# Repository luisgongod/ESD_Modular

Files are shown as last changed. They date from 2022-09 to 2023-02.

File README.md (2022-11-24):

# E.S.D.
<!-- 
 _____ _____ ____  
|   __|   __|    \ 
|   __|__   |  |  |
|_____|_____|____/ 
 -->

Main repo for *ESD* Eurorack modules. 

## !!! Attention: Both Models are under Beta, bugs and fixes are in process !!!

- [*Model 14*](https://github.com/luisgongod/ESD_Modular/tree/main/model_14): an inspired _EuroPi_ module with 4 extra CVs, 4 Pots, 1 Digital Inpu, Bigger screen and I/O headers
- [*Model 15*](https://github.com/luisgongod/ESD_Modular/tree/main/model_15): Remix of the OG _EuroPi_ adding CV to the existing Pots and I/O headers for external modules

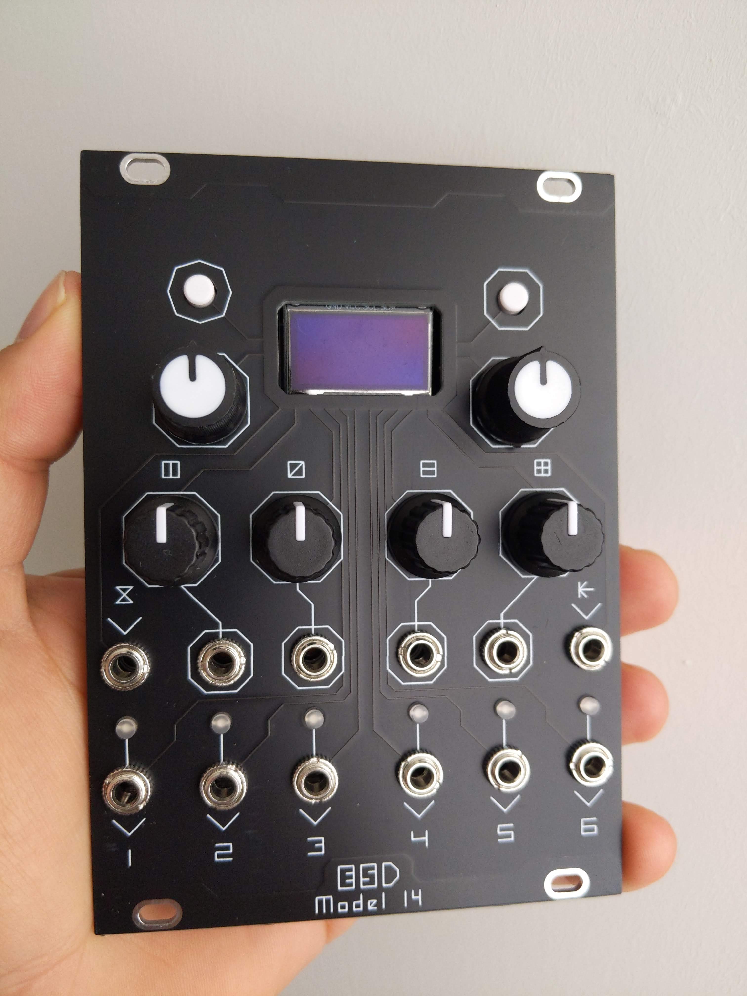
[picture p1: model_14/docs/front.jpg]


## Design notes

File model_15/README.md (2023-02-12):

# Model 15

Programable Eurorack module Remix of by Allen-Synthesis' [EuroPi](https://github.com/Allen-Synthesis/EuroPi).

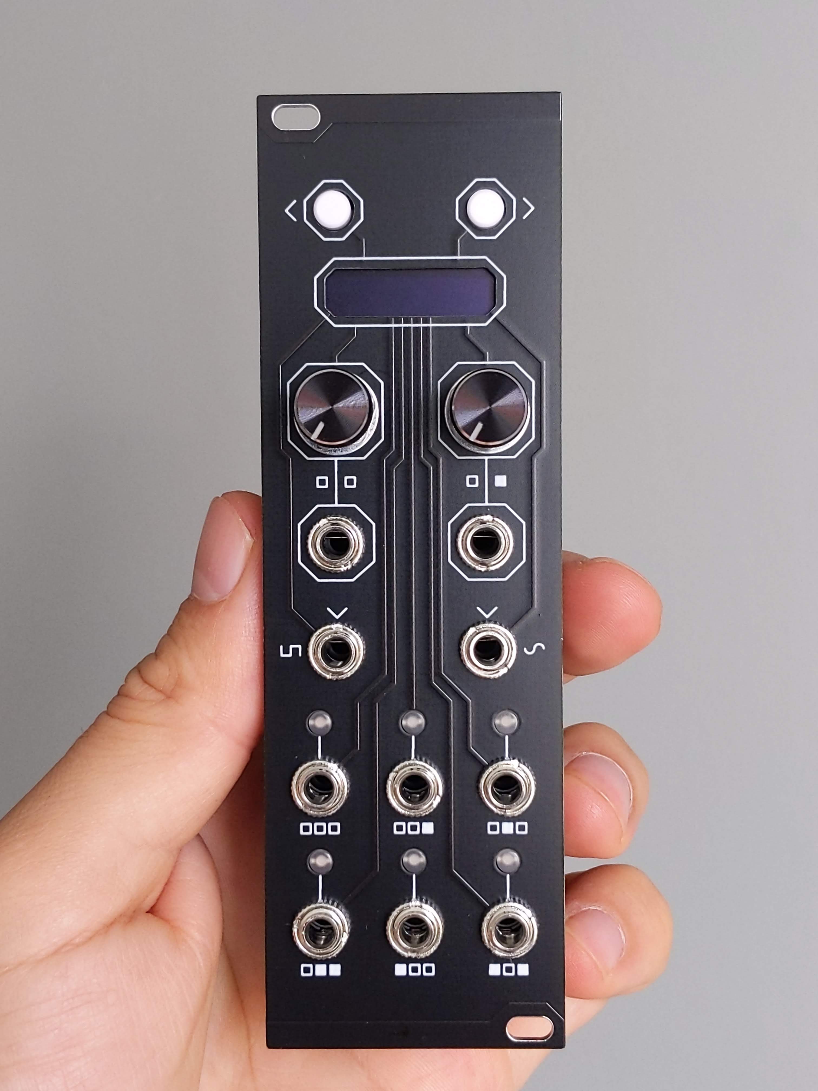
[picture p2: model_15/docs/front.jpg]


## Description

This module is based on the schematics of the EuroPi, the slight differences:

- Added CV to the Knobs (analogue input)
- Access to un-used pins thru a header (for expansions)
- Jumper to change analog input from bipolar-unipolar* (Experimental! see TODOS)

This module is fully compatible with all Europi [scripts](https://github.com/Allen-Synthesis/EuroPi/tree/main/software/contrib) as long as the modified firmware is used `europi_m15.py`.

## TODOs:

- Better Diagnosis Script
- Change Calibration to acommodate bipolar and inverted Analog signal
- Add Bipolar support (change fw)

## Get your own

Under `hardwared` you can find the gerbers and BOM files. This gerber was done to be printed in one go, a v-cut is used to separate both pcnbs. Be careful about it when ordering. Exported files to `altium` are also included but _atention_ these were not verified (i dont have altium)

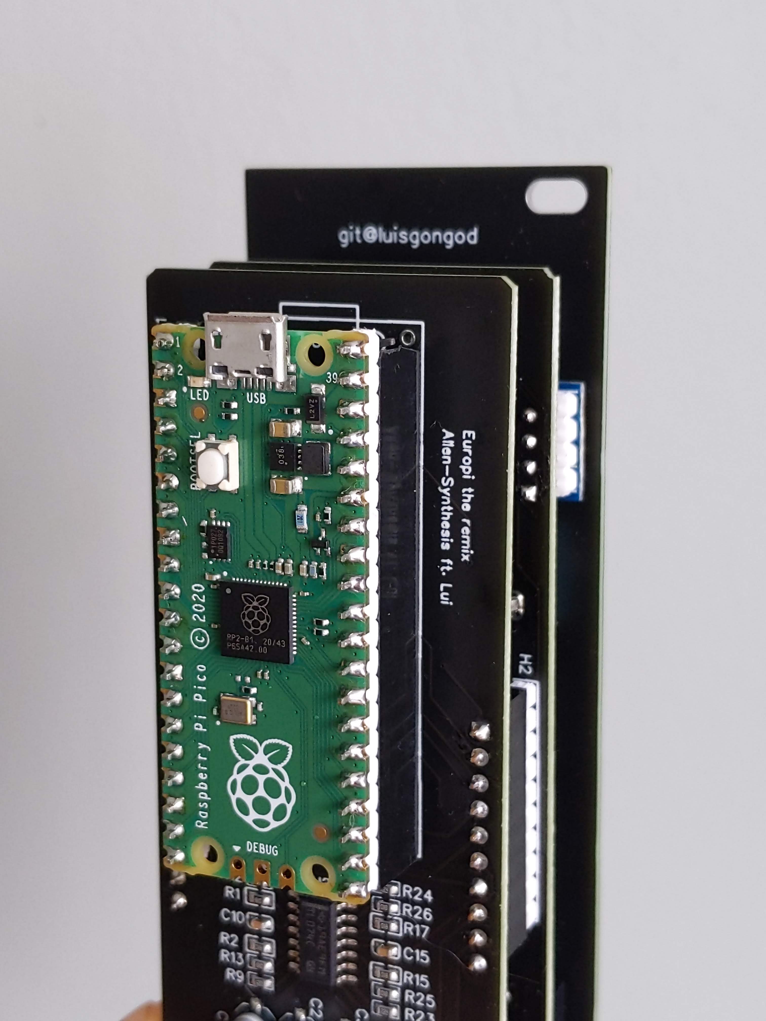
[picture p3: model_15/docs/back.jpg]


## Get Started

You can use the same setup as decribed in EuroPi's page ([here](https://github.com/Allen-Synthesis/EuroPi/blob/main/software/programming_instructions.md)). 

If you want to use `menu.py` script as `main.py`. Use `ampy` pip package to move files to the `contrib` folder

```
 C:\EuroPi-main\software> ampy  --port COM21 put contrib /lib/contrib
```
 
Other useful `ampy` commands can be found [here](https://learn.adafruit.com/micropython-basics-load-files-and-run-code/file-operations)

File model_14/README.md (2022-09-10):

# Model 14

Programable Eurorack module inspired by Allen-Synthesis' [EuroPi](https://github.com/Allen-Synthesis/EuroPi).



## Description

This module is based on the schematics of the EuroPi, the main differences are:

- 7 extra Analogue inputs thanks to a multiplexer
- Larger 128x64 Oled display
- Extra digital input
- Access to un-used pins thru a header (for expansions)
- Jumper to change analog input from bipolar-unipolar or range (10Vpp or 5Vpp)

This module is fully compatible with all Europi [scripts](https://github.com/Allen-Synthesis/EuroPi/tree/main/software/contrib) using the midified firmware `europi_m14.py` (more details below).

## Get your own

Under `hardwared` you can find the gerbers and BOM files. _Caution_,  this last version of the hardware files was not produced, there was a small bug: the LEDs where not connected, you can see maybe that the ground needed to be wire in:

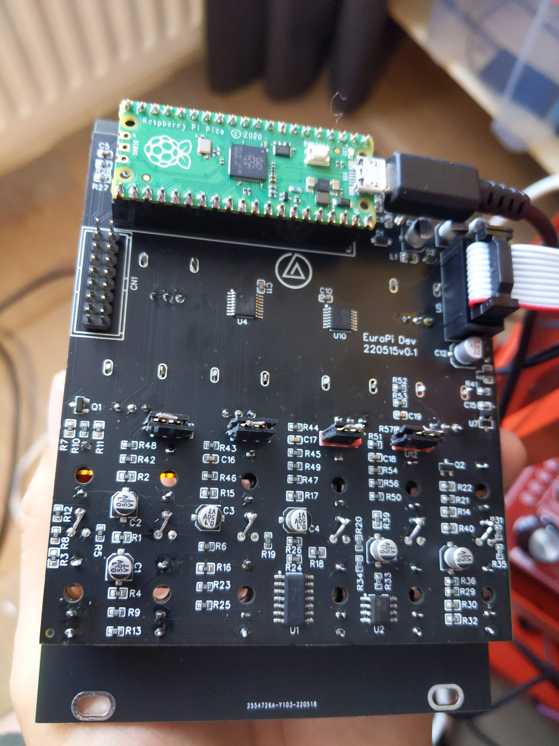
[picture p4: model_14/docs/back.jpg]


However I am confident that the module will work if manufactured as it is. Some assistant to debugging could be provided. Components are relatively easty to source and because of the nature of the I/O there is no need for high accuracy resistors (1% is ok). Calibrating the module is a most.

## Get Started

You can use the same setup as decribed in EuroPi's page ([here](https://github.com/Allen-Synthesis/EuroPi/blob/main/software/programming_instructions.md)). Once everything is installed, you can save the `europi_m14.py` file in the `libs` folder. You can also change the name and overwrite the `europi.py`, this will make all original scripts work right away. 
I have modified some of the scripts from the compilation to work with _model 14_. In this scripts I use the suffix `m14` to differenciate from originals. All credits to original authors should be in the code itself.

## To continue

This was an experiment to make my own definition/expanse of the Europi. I faced a few challenges but learn a lot. I want to focus on a different version. Perhaps if more people gets involved in increassing the scripts.

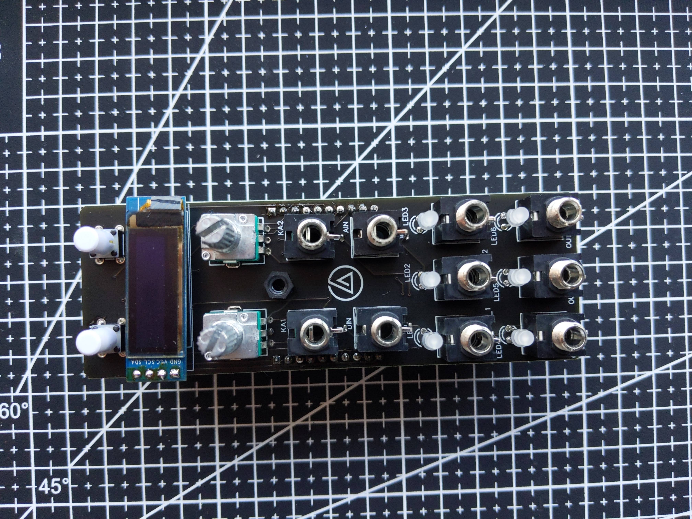
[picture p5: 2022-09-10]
model_15/docs/front_io.jpg

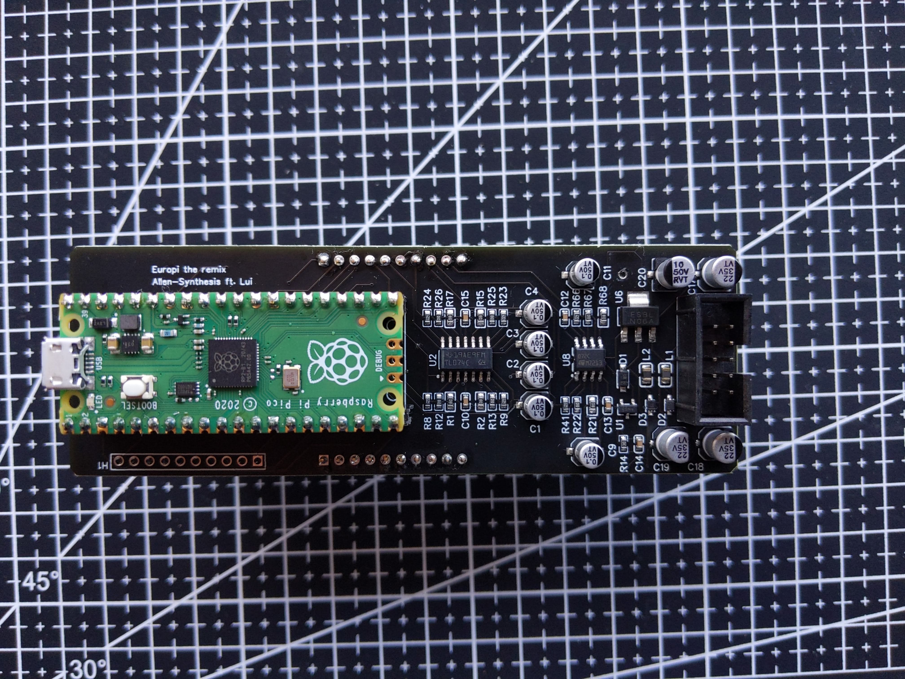
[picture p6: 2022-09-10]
model_15/docs/back_io.jpg

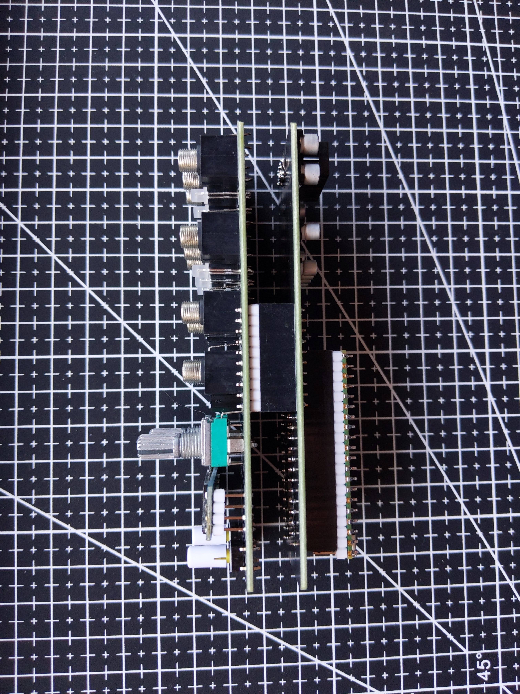
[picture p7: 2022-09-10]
model_15/docs/side.jpg

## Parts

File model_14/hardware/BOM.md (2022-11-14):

# BOM Model 14
| ID | Name | Designator | Footprint | Quantity |
|----|---|---|---|---|
| 1  | 0.1uF | C1,C2,C3,C4,C6,C7 | CAP-SMD_BD4.0-L4.3-W4.3-FD | 6 |
| 2  | 100nF | C5,C8,C10,C11,C15 | C0603 | 5 |
| 3  | 22uF | C9,C12,C14 | CAP-SMD_BD5.0-L5.3-W5.3-FD | 3 |
| 4  | 10uF | C13 | CAP-SMD_BD5.0-L5.3-W5.3-FD | 1 |
| 5  | 10nF | C16,C17,C18,C19 | C0603 | 4 |
| 6  | THONKICONN JACK | CV1,CV2,IN1,IN2,IN3,IN4,OUT_1,OUT_2,OUT_3,OUT_4,OUT_5,OUT_6 | THONKICONN_JACK | 12 |
| 7  | 1N4148W_C81598 | D1 | SOD-123F_L2.7-W1.6-LS3.8-RD | 1 |
| 8  | 1N5819WS | D2,D3 | SOD-323_L1.8-W1.3-LS2.5-RD | 2 |
| 9  | KH-A2541WV-8P | H1 | HDR-TH_8P-P2.54-V-M | 1 |
| 10 | 600Ω | L1,L2 | L0805 | 2 |
| 11 | 204-10SURD/S530-A3-L | LED1,LED2,LED3,LED4,LED5,LED6 | LED-TH_BD3.0-P2.54-FD | 6 |
| 12 | B100K | PT-CV1,PT-CV2,PT-PAR1,PT-PAR2,PT-PAR3,PT-PAR4 | ALPHA9MM_TRIM | 6 |
| 13 | MMBT3904-C20526 | Q1,Q2 | SOT-23-3_L2.9-W1.3-P1.90-LS2.4-BR | 2 |
| 14 | 1K | R1,R2,R3,R4,R15,R16,R17,R18,R28,R30,R32,R38,R39,R40 | R0603 | 14 |
| 15 | 4.7kΩ | R5,R6,R19,R20,R29,R31 | R0603 | 6 |
| 16 | 300kΩ | R7,R14,R50,R52,R60,R61,R62,R63 | R0603 | 8 |
| 17 | 220kΩ | R8,R9,R23,R24,R34,R35 | R0603 | 6 |
| 18 | 100kΩ | R10,R12,R13,R21,R25,R26,R33,R36,R51,R53,R64,R65 | R0603 | 12 |
| 19 | 10kΩ | R27,R37,R58,R59 | R0603 | 4 |
| 20 | 2.2kΩ | R41 | R0603 | 1 |
| 21 | 1MΩ | R42,R43 | R0603 | 2 |
| 22 | 150kΩ | R54,R55,R56,R57 | R0603 | 4 |
| 23 | TL1105SPF250Q | SW1,SW2 | KEY-TH_4P-L6.0-W6.0-P4.50-LS7.5 | 2 |
| 24 | TL072CDT | U2 | SOIC-8_L5.0-W4.0-P1.27-LS6.0-BL | 1 |
| 25 | DISPLAY-OLED-128X64  | U3 |DISPLAY-OLED-128X64 | 1 |
| 26 | 74HC4051PW,118 | U4 | TSSOP-16_L5.0-W4.4-P0.65-LS6.4-BL  | 1 |
| 27 | 1761608-3 | U5 | IDC-TH_10P-P2.54-S2.54_L9.2-W20.3  | 1 |
| 28 | LM1117MP-5.0/TR | U6 | SOT-223-3_L6.5-W3.4-P2.30-LS7.0-BR | 1 |
| 29 | LM4040C10IDBZR | U7 | SOT-23-3_L3.0-W1.7-P0.95-LS2.9-BR  | 1 |
| 30 | JUMPER3 | U8,U9,U11,U12 | HDR-TH_3P-P2.54-V-M-A | 4 |
| 31 | RASPBERRY-PI-PICO | U13 | RASPBERRY-PI-PICO | 1 |
| 32 | TL074CDR | U1 | SOIC-14_L8.7-W3.9-P1.27-LS6.0-BL | 1 |
| 33 | MCP6004T-I/ST | U10 | TSSOP-14_L5.0-W4.4-P0.65-LS6.4-BL  | 1 |
| 34 | 1RWHT | B1,B2 | ButtonSwitch Caps  | 2 |

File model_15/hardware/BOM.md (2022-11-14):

# BOM Model 15

| ID | Name | Designator | Footprint | Quantity  |
|----|---|---|---|---|
| 1  | DISPLAY-OLED-128X32 | 1 | DISPLAY-OLED-128X32 | 1 |
| 2  | THONKICONN JACK | AIN,DIN,KA1,KA2,OUT_1,OUT_2,OUT_3,OUT_4,OUT_5,OUT_6 | THONKICONN_JACK | 10 |
| 3  | 0.1uF | C1,C2,C3,C4,C9,C11 | CAP-SMD_BD4.0-L4.3-W4.3-FD | 6 |
| 4  | 100nF | C5,C8,C10,C12,C13,C14,C15,C16 | C0603 | 8 |
| 5  | 10nF | C6,C7,C21 | C0603 | 3 |
| 6  | 22uF | C17,C18,C19 | CAP-SMD_BD5.0-L5.3-W5.3-FD | 3 |
| 7  | 10uF | C20 | CAP-SMD_BD5.0-L5.3-W5.3-FD | 1 |
| 8  | 1N4148W_C81598 | D1 | SOD-123F_L2.7-W1.6-LS3.8-RD | 1 |
| 9  | 1N5819WS | D2,D3 | SOD-323_L1.8-W1.3-LS2.5-RD | 2 |
| 10 | Header-Male-2.54_1x10 | H1,H2,H4,H5,H6 | HDR-TH_10P-P2.54-V-M-1 | 5 |
| 11 | B100K | K1,K2 | ALPHA9MM_TRIM | 2 |
| 12 | 600Ω | L1,L2 | L0805 | 2 |
| 13 | 204-10SURD/S530-A3-L  | LED1,LED2,LED3,LED4,LED5,LED6 | LED-TH_BD3.0-P2.54-FD | 6 |
| 14 | PAD | PIN1 | PADPAD | 1 |
| 15 | MMBT3904-C20526 | Q1 | SOT-23-3_L2.9-W1.3-P1.90-LS2.4-BR | 1 |
| 16 | 1K | R1,R2,R3,R4,R15,R16,R17,R18,R21,R28,R38,R55,R64,R68 | R0603 | 14 |
| 17 | 4.7kΩ | R5,R6,R19,R20,R54,R65 | R0603 | 6 |
| 18 | 100kΩ | R7,R10,R12,R13,R22,R25,R26,R31,R39,R67 | R0603 | 10 |
| 19 | 220kΩ | R8,R9,R23,R24,R41,R66 | R0603 | 6 |
| 20 | 1MΩ | R11 | R0603 | 1  |
| 21 | 10kΩ | R14,R27,R37,R58 | R0603 | 4  |
| 22 | 150kΩ | R29,R30,R33,R34 | R0603 | 4  |
| 23 | 300kΩ | R32,R35,R36,R42,R43 | R0603 | 5  |
| 24 | TL1105SPF250Q | SW1,SW2 | KEY-TH_4P-L6.0-W6.0-P4.50-LS7.5 | 2  |
| 25 | LM4040C10IDBZR | U1 | SOT-23-3_L3.0-W1.7-P0.95-LS2.9-BR  | 1  |
| 26 | 1761608-3 | U5 | IDC-TH_10P-P2.54-S2.54_L9.2-W20.3  | 1  |
| 27 | LM1117MP-5.0/TR | U6 | SOT-223-3_L6.5-W3.4-P2.30-LS7.0-BR | 1  |
| 28 | TL072CDT | U8 | SOIC-8_L5.0-W4.0-P1.27-LS6.0-BL | 1  |
| 29 | RASPBERRY-PI-PICO | U13 | RASPBERRY-PI-PICO | 1  |
| 30 | TL074CDR | U2 | SOIC-14_L8.7-W3.9-P1.27-LS6.0-BL | 1  |
| 31 | MCP6004T-I/ST | U7 | TSSOP-14_L5.0-W4.4-P0.65-LS6.4-BL  | 1  |
| 32 | 1RWHT | B1,B2 | ButtonSwitch Caps  | 2 |

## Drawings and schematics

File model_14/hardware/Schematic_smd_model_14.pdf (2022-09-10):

# OUTPUTS

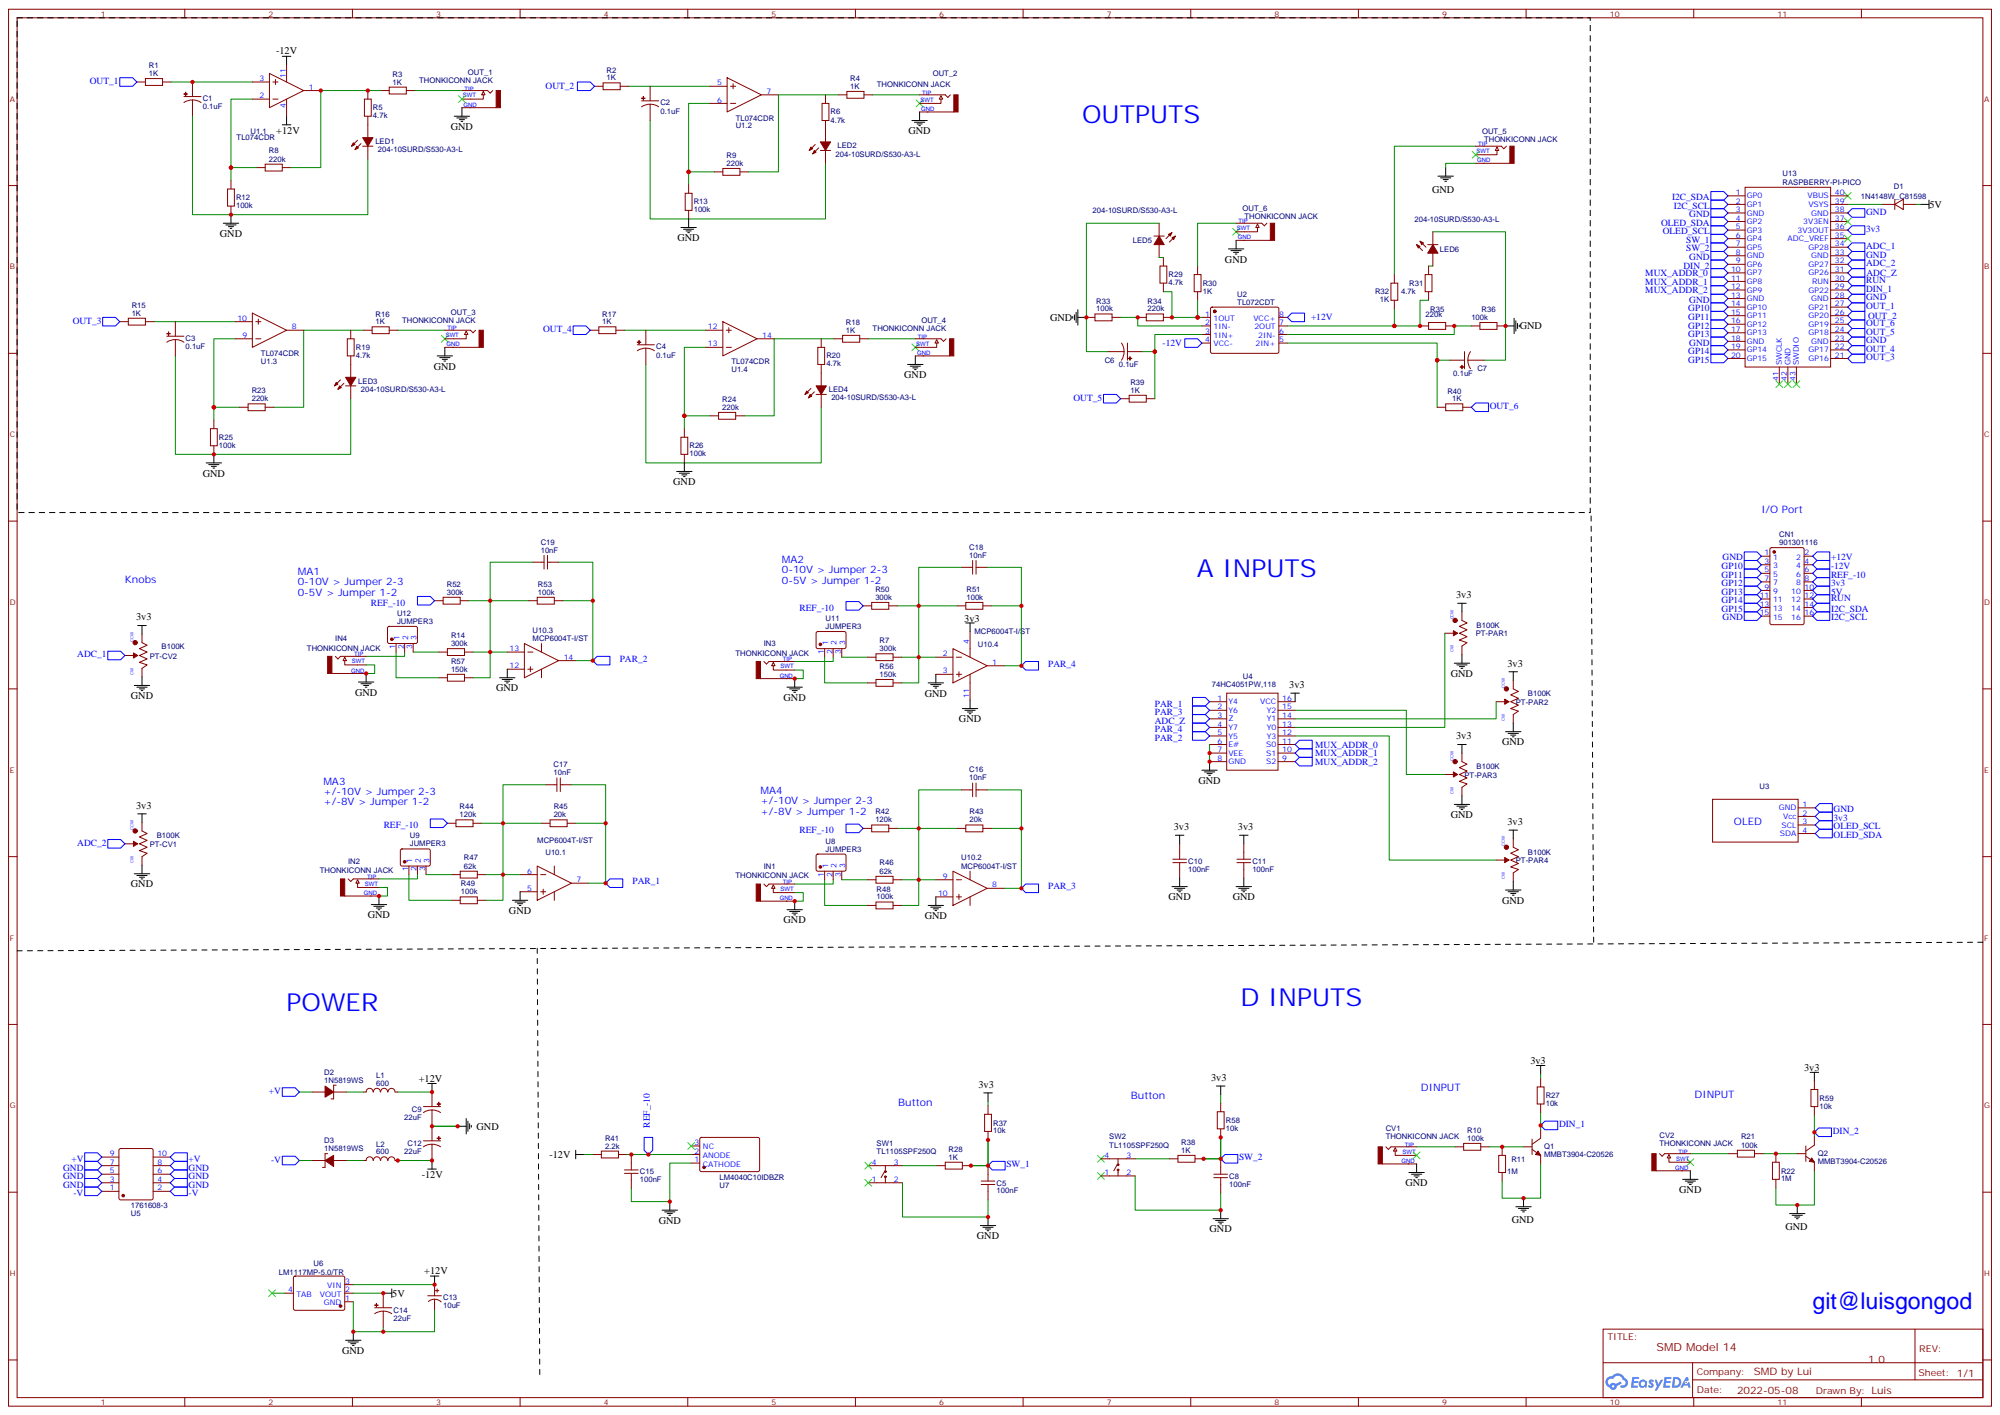
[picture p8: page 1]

Company: SMD by Lui

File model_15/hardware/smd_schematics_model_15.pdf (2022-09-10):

# OUT

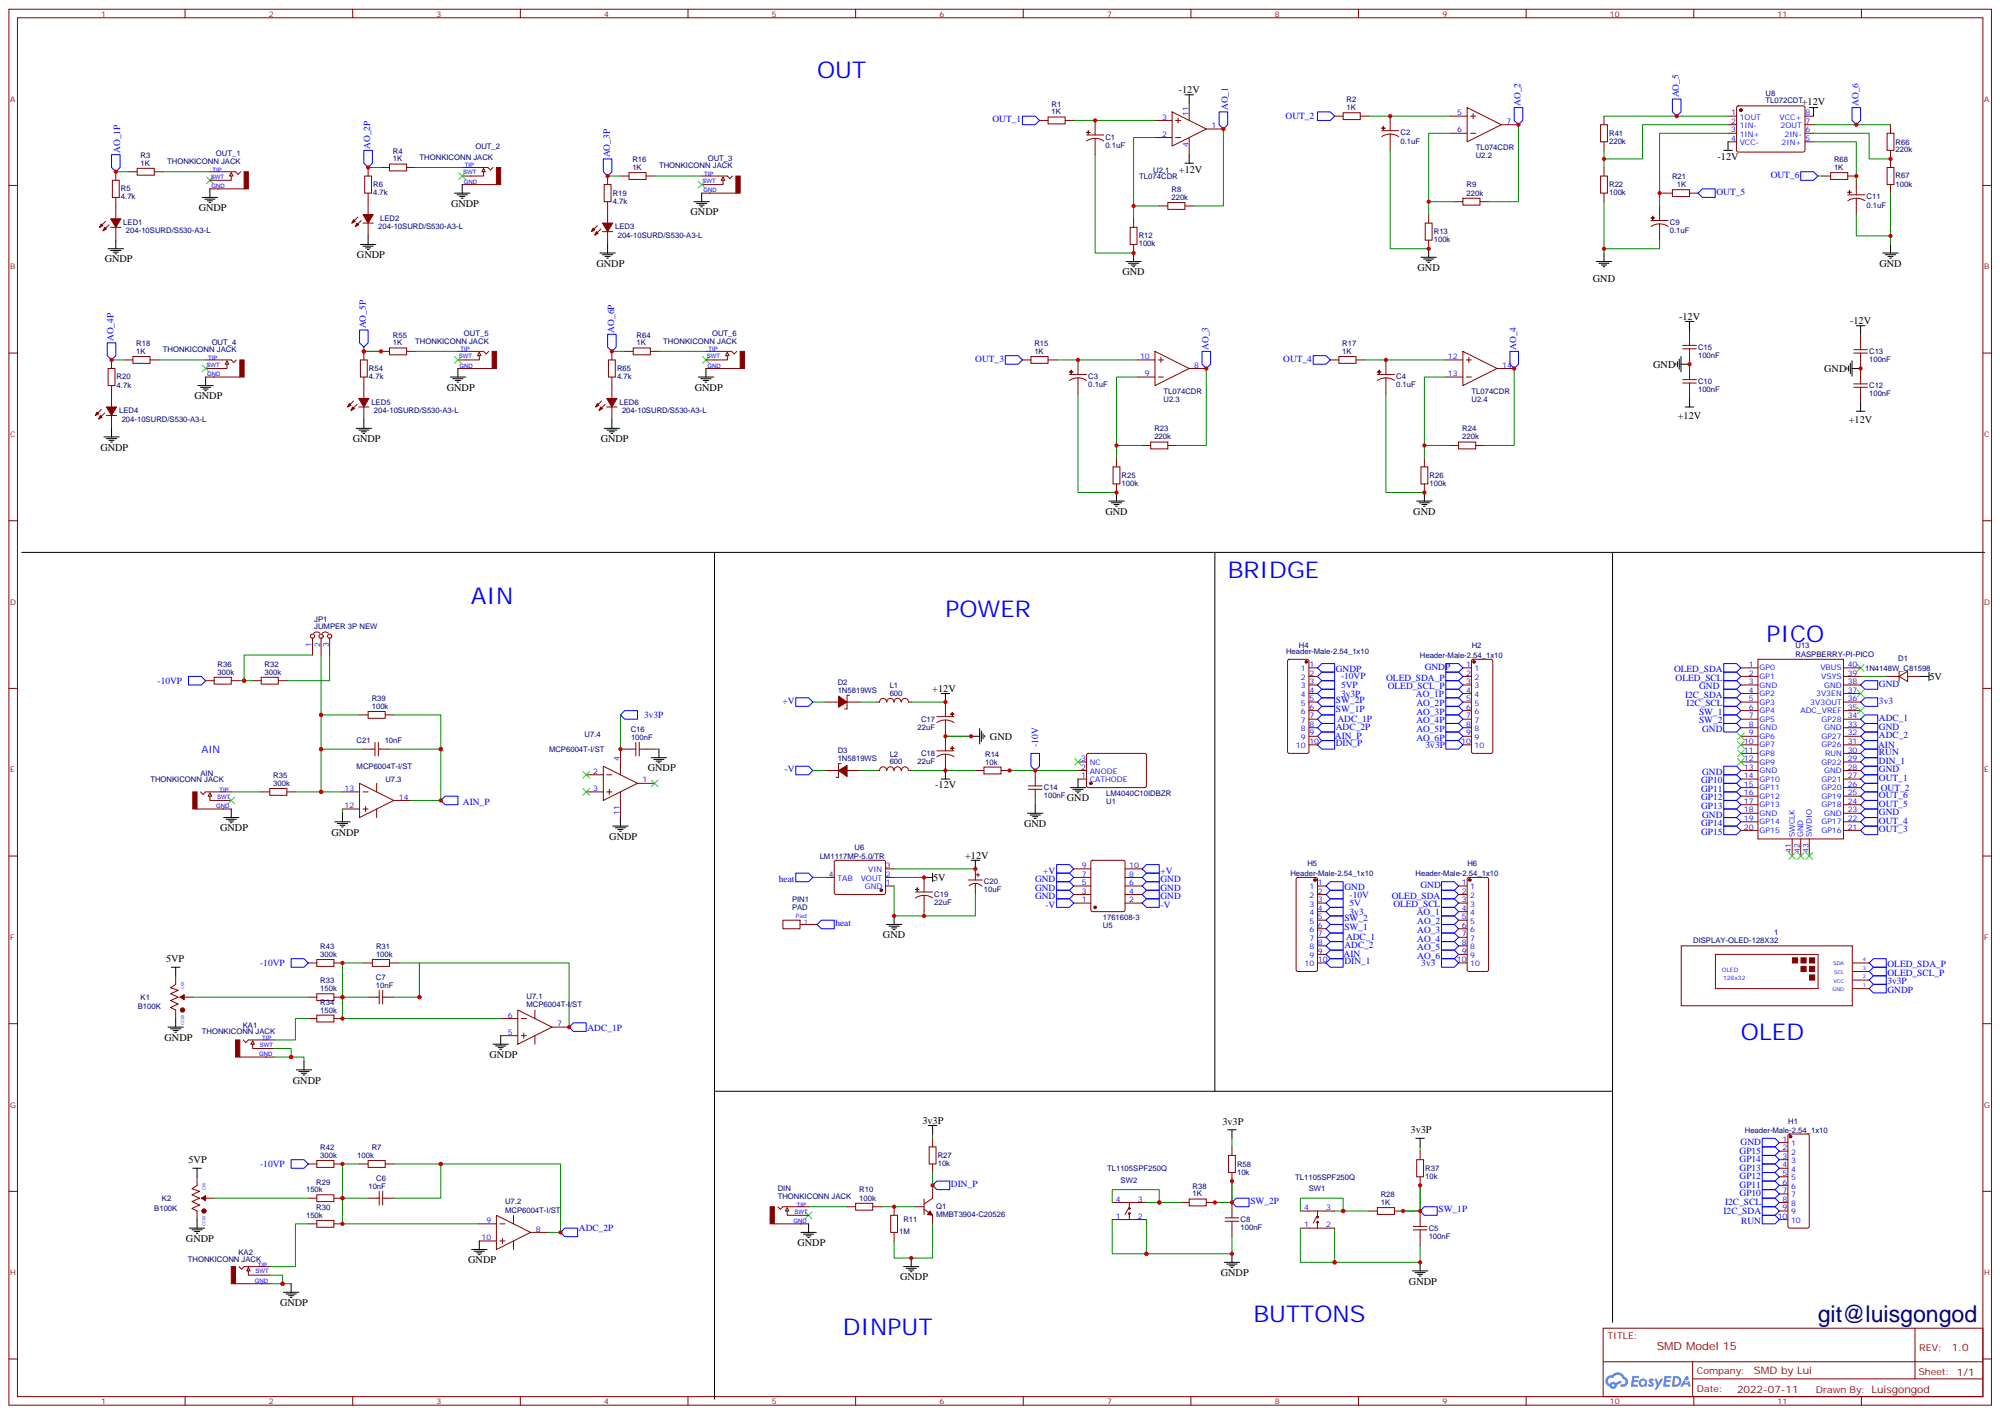
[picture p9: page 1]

Company: SMD by Lui

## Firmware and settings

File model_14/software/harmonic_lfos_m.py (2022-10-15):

from europi_m14 import *
from math import cos, radians
from time import sleep_ms
from machine import freq
from random import randint
from europi_script import EuroPiScript

MAX_VOLTAGE = MAX_OUTPUT_VOLTAGE #Default is inherited but this can be overriden by replacing "MAX_OUTPUT_VOLTAGE" with an integer
MAX_HARMONIC = 32 #Too high a value may be hard to select using the knob, but the actual hardware limit is only reached at 4096

class HarmonicLFOs(EuroPiScript):
    def __init__(self):
        super().__init__()
        
        #Retreive saved state information from file
        state = self.load_state_json()
        
        #Overclock the Pico for improved performance
        freq(250_000_000)
        
        #Use the saved values for the LFO divisions and mode if found in the save state file, using defaults if not
        # self.divisions = state.get("divisions", [1, 3, 5, 7, 11, 13])
        self.divisions = state.get("divisions", [1, 2, 4, 8, 16, 32])
        self.DIVSISION_CHOICES = [1, 2, 4, 8, 16, 32]
        self.modes = state.get("modes", [0, 0, 0, 0, 0, 0])
        self.MODE_COUNT = 5
        
        #Initialise all the other variables
        self.degree = 0
        self.delay, self.increment_value = self.get_delay_increment_value()
        self.pixel_x = OLED_WIDTH-1
        self.pixel_y = int(OLED_HEIGHT/2)-1
        self.selected_lfo = 0
        self.selected_lfo_start_value = self.get_clock_division()
        
        #Set the digital input and button handlers
        din.handler(self.reset)
        b1.handler(self.change_mode)
        b2.handler(self.increment_selection)

    def get_clock_division(self):
        """Determine the new clock division based on the position of knob 2"""       

        # return k2.read_position(MAX_HARMONIC) + 1
        return k2.choice([1, 2, 4, 8, 16, 32])

    def reset(self):
        """Reset all LFOs to zero volts, maintaining their divisions"""
        self.degree = 0

    def change_mode(self):
        """Change the mode that controls wave shape"""
        self.modes[self.selected_lfo] = (self.modes[self.selected_lfo] + 1) % self.MODE_COUNT
        self.save_state()

    def get_delay_increment_value(self):
        """Calculate the wait time between degrees"""
        # delay = (0.1 - (k1.read_position(100, 1)/1000)) + (ain.read_voltage(1)/100)
        delay = (0.1 - (k1.read_position(100, 1)/1000)) 
        return delay, round((((1/delay)-10)/1)+1)

    def increment_selection(self):
        """Move the selection to the next LFO"""
        self.selected_lfo = (self.selected_lfo + 1) % 6
        self.selected_lfo_start_value = self.get_clock_division()

    def save_state(self):
        """Save the current set of divisions to file"""
        if self.last_saved() < 5000:
            return
        
        state = {
            "divisions": self.divisions,
            "modes": self.modes
        }
        self.save_state_json(state)
        
    def update_display(self):
        """Update the OLED display every 10 cycles (degrees)"""
        oled.scroll(-1,0)
        if round(self.degree, -1) % 10 == 0:
            oled.show()
            
    def increment(self):
        """Increment the current degree and determine new values of delay and increment_value"""
        self.degree += self.increment_value
        self.delay, self.increment_value = self.get_delay_increment_value()
        sleep_ms(int(self.delay))
        
    def draw_wave(self,lfo=0):
        shape = self.modes[lfo]
        position = lfo*21
        if shape == 0: #Sine
            oled.pixel(position + 3,31,1)
            oled.pixel(position + 3,30,1)
            oled.pixel(position + 3,29,1)
            oled.pixel(position + 4,28,1)
            oled.pixel(position + 4,27,1)
            oled.pixel(position + 4,26,1)
            oled.pixel(position + 4,25,1)
            oled.pixel(position + 5,24,1)
            oled.pixel(position + 6,23,1)
            oled.pixel(position + 7,23,1)
            oled.pixel(position + 8,24,1)
            oled.pixel(position + 9,25,1)
            oled.pixel(position + 9,26,1)
            oled.pixel(position + 9,27,1)
            oled.pixel(position + 10,28,1)
            oled.pixel(position + 10,29,1)
            oled.pixel(position + 11,30,1)
            oled.pixel(position + 12,31,1)
            oled.pixel(position + 13,31,1)
            oled.pixel(position + 14,30,1)
            oled.pixel(position + 15,29,1)
            oled.pixel(position + 15,28,1)
            oled.pixel(position + 15,27,1)
            oled.pixel(position + 15,26,1)
            oled.pixel(position + 16,25,1)
            oled.pixel(position + 16,24,1)
            oled.pixel(position + 16,23,1)
        elif shape == 1: #Saw
            oled.line( position + 3 ,31 ,position + 9,24,1)
            oled.vline(position + 9 ,24 ,8,1)
            oled.line( position + 9 ,31 ,position + 15,24,1)
            oled.vline(position + 15,24 ,8,1)
        elif shape == 2: #Square
            oled.vline(position + 3,24,8,1)
            oled.hline(position + 3,24,6,1)
            oled.vline(position + 9,24,8,1)
            oled.hline(position + 9,31,6,1)
            oled.vline(position + 15,24,8,1)
        elif shape == 3: #Ramp
            oled.vline(position + 3,24 ,8,1)
            oled.line( position + 3 ,24 ,position + 9,31,1)
            oled.vline(position + 9 ,24 ,8,1)
            oled.line( position + 9 ,24 ,position + 15,31,1)
        elif shape == 4: #Random(ish)
            oled.pixel(position + 3,29,1)
            oled.pixel(position + 4,28,1)
            oled.pixel(position + 4,27,1)
            oled.pixel(position + 5,26,1)
            oled.pixel(position + 6,26,1)
            oled.pixel(position + 7,27,1)
            oled.pixel(position + 8,28,1)
            oled.pixel(position + 9,28,1)
            oled.pixel(position + 10,27,1)
            oled.pixel(position + 10,26,1)
            oled.pixel(position + 10,25,1)
            oled.pixel(position + 11,24,1)
            oled.pixel(position + 12,25,1)
            oled.pixel(position + 13,26,1)
            oled.pixel(position + 13,27,1)
            oled.pixel(position + 14,28,1)
            oled.pixel(position + 14,29,1)
            oled.pixel(position + 15,30,1)
            oled.pixel(position + 16,30,1)        
        
    def display_selected_lfo(self,lfo=0):
        """Draw the current LFO's number and division to the OLED display"""

        oled.fill_rect(21*lfo,0,20,32,0)
        if lfo == self.selected_lfo:
            oled.rect(21*lfo,0,20,32,1)

        # oled.fill_rect(21*lfo,0,20,9,1)
        
        oled.text(str(lfo+1),6+21*lfo,1,1)        
        # number = self.divisions[self.selected_lfo]
        number = self.divisions[lfo]
        x = 2 if number >= 10 else 6
        oled.text(str(number),x+21*lfo,12,1)
        
        self.draw_wave(lfo)
        
    def round_nearest(self, x, a):
        return round(x / a) * a
        
    def calculate_voltage(self, cv, multiplier):
        """Determine the voltage based on current degree, wave shape, and MAX_VOLTAGE"""
        three_sixty = 360*multiplier
        degree_three_sixty = self.degree % three_sixty
        lfo_mode = self.modes[cvs.index(cv)]
        if lfo_mode == 0: #Sin
            voltage = ((0-(cos(self.rad*(1/multiplier)))+1)) * (MAX_VOLTAGE/2)
        elif lfo_mode == 1: #Saw
            voltage = (degree_three_sixty / (three_sixty)) * MAX_VOLTAGE
        elif lfo_mode == 2: #Square
            voltage = MAX_VOLTAGE * (int((degree_three_sixty / (three_sixty)) * MAX_VOLTAGE) < (MAX_VOLTAGE/2))
        elif lfo_mode == 3: #Off
            voltage = MAX_VOLTAGE -((degree_three_sixty / (three_sixty)) * MAX_VOLTAGE)
        elif lfo_mode == 4: #Random(ish). This is NOT actually random, it is the sum of 3 out of sync sine waves, but it produces a flucutating voltage that is near impossible to predict over time, and which can be clocked to be in time
            voltage = ((((0-(cos(self.rad*(1/multiplier)))+1)) * (MAX_VOLTAGE/2)) / 3) + ((((0-(cos(self.rad*(1/(multiplier*2.3))))+1)) * (MAX_VOLTAGE/2)) / 3) + ((((0-(cos(self.rad*(1/(multiplier*5.6))))+1)) * (MAX_VOLTAGE/2)) / 3)
        return voltage
        
    def display_graphic_lines(self):
        """Draw the lines displaying each LFO's voltage to the OLED display"""
        self.rad = radians(self.degree)
        oled.vline(self.pixel_x,0,OLED_HEIGHT,0)
        for cv, multiplier in zip(cvs, self.divisions):
            volts = self.calculate_voltage(cv, multiplier)
            cv.voltage(volts)
            oled.pixel(self.pixel_x,self.pixel_y+self.pixel_y-int(volts*(self.pixel_y/10)),1)

    def check_change_clock_division(self):
        """Change current LFO's division with knob movement detection"""
        self.clock_division = self.get_clock_division()

        self.divisions[0] = 1
        self.divisions[1] = mks[0].read_position(MAX_HARMONIC)+1
        self.divisions[2] = mks[1].read_position(MAX_HARMONIC)+1
        self.divisions[3] = mks[2].read_position(MAX_HARMONIC)+1
        self.divisions[4] = mks[3].read_position(MAX_HARMONIC)+1
        self.divisions[5] = k2.read_position(MAX_HARMONIC)+1


        # if self.clock_division != self.selected_lfo_start_value:
            # self.selected_lfo_start_value = self.clock_division 
            # self.divisions[self.selected_lfo] = self.clock_division
            # self.save_state()
        

    def main(self):
        while True:
            self.check_change_clock_division()
            
            self.display_graphic_lines()
            
            for lfo_num in range(6):
                self.display_selected_lfo(lfo_num)
            
            self.update_display()
            
            self.increment()


if __name__ == "__main__":
    HarmonicLFOs().main()

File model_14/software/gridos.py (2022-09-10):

from europi_m14 import *
import machine
from time import ticks_diff, ticks_ms
from random import randint, uniform
from europi_script import EuroPiScript
from bjorklund import bjorklund as eucledian_rhythm

'''
GriDos
author: Luis G (github.com/luisgongod)
labels: sequencer, triggers, drums, randomness

A gate sequencer that builds on Nik Ansell's Consequencer. 

Inspired by Grids from mutable instruments. 
Can control up 6 instruments, adding sequences for each channel
Perfect to use with something like the Weston Audio AD110

CONTROLS:
knob_1: Randomness
knob_2: Fill, based on euclediaan rhythms

digital_in: clock in
analog_in: CV for Randomness, Fill or Pattern

button_1: 
- Short Press  (<300ms)  : Previous Drum pattern
- Medium Press (>300ms)  : Cycles through clock divisors (1/1, 1/2, 1/4)
- Long Press  (>2000ms)  : ??? TBD

button_2:
- Short Press  (<300ms)  : Next Drum pattern
- Medium Press (>300ms)  : Cycles what AIN can CV, (randomness -> fill -> Pattern -> randomness)
- Long Press   (>2000ms) : Toggle option for Random/Fill behaviour mode, 
    &: Randomness will change if a fill-step will be trigger
    |: Randomness will change in a fill-step if Patterns are triggered

output_1: trigger 1 / Bass Drum
output_2: trigger 2 / Snare Drum
output_3: trigger 3 / Hi-Hat
output_4: trigger 4 / Closed-Hat 
output_5: trigger 5 / Cymmbal
output_6: trigger 6 / Clap

'''

class Consequencer(EuroPiScript):
    def __init__(self):
        # Overclock the Pico for improved performance.
        machine.freq(250_000_000)

        # Initialize sequencer pattern arrays   
        p = pattern()     
        self.BD=p.BD
        self.SN=p.SN
        self.HH=p.HH
        self.OH=p.OH
        self.CY=p.CY
        self.CL=p.CL

        self.AIN_MODE = ['Random', 'Fill', 'Pattern']
        self.CLOCK_DIVISORS = [1, 2, 4]        

        # Initialize variables
        self.step = 0
        self.trigger_duration_ms = 50
        self.clock_step = 0
        self.clock_divisor = 0
        self.base_pattern = 0
        self.extra_pattern = 0
        self.pattern = 0
        self.random_HH = False
        self.minAnalogInputVoltage = 0.9 # Minimum voltage for analog input to be considered
        self.randomness = 0
        self.analogInputMode = 1 # initial mode 0: Randomness, 1: Fill, 2: Pattern 
        self.rand_fill_mode = 0 #  0: Random && Fill, 1: Random >> Fill
        self.CvPattern = 0
        self.reset_timeout = 500
        
        self.step_length = len(self.BD[self.pattern])

        self.fill = []
        
        # Calculate the longest pattern length to be used when generating random sequences
        self.maxStepLength = len(max(self.BD, key=len))
      

        # Triggered when button 2 is released.
        # - Short Press  (<300ms)  : Next Drum pattern
        # - Medium Press (>300ms)  : Cycles what AIN can CV, (randomness -> fill -> Pattern -> randomness)
        # - Long Press   (>2000ms) : Toggle option for Random/Fill behaviour mode, 
        @b2.handler_falling
        def b2Pressed():
            #Toggle Random/Fill mode
            # if more modes are added, this will need to be updated
            #     &: Random applies only to Filled steps
            #     |: Random applies to all steps if > 0
            if ticks_diff(ticks_ms(), b2.last_pressed()) >  2000:
                self.rand_fill_mode = not(self.rand_fill_mode)
            
            # AIN CV mode
            elif ticks_diff(ticks_ms(), b2.last_pressed()) >  300:
                self.analogInputMode = self.analogInputMode + 1
                if self.analogInputMode >= len(self.AIN_MODE):
                    self.analogInputMode = 0
            
            #next drum pattern
            else:
                self.base_pattern = (self.base_pattern + 1)%len(self.BD)
                self.pattern = (self.base_pattern + self.extra_pattern)%len(self.BD)
                self.step_length = len(self.BD[self.pattern])
            
        # - Short Press  (<300ms)  : Previous Drum pattern
        # - Medium Press (>300ms)  : Cycles through clock divisors (1/1, 1/2, 1/4)
        # - Long Press   (>2000ms) : ???
        @b1.handler_falling
        def b1Pressed():
            if ticks_diff(ticks_ms(), b1.last_pressed()) >  2000:
                pass
            
            # clock divisor
            elif ticks_diff(ticks_ms(), b1.last_pressed()) >  300:
                self.clock_divisor = (self.clock_divisor + 1) % len(self.CLOCK_DIVISORS)
            
            #prev drum pattern
            else:                
                self.base_pattern = (self.base_pattern - 1)%len(self.BD)
                self.pattern = (self.base_pattern + self.extra_pattern)%len(self.BD)
                self.step_length = len(self.BD[self.pattern])

        # Triggered on each clock into digital input. Output triggers.
        @din.handler
        def clockTrigger():

            # function timing code. Leave in and activate as needed
            #t = time.ticks_us()
            
            self.step_length = len(self.BD[self.pattern])
            
            # A pattern was selected which is shorter than the current step. Set to zero to avoid an error
            if self.step >= self.step_length:
                self.step = 0
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

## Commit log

2022-07-24 🎉 lets start simulating ssss
2022-07-30 🎉 model 14
2022-07-30 🎉 importing euripi_m
2022-07-31 🤡 bipolar sim
2022-08-07 ✅ add smooth out in diagnosis
2022-08-10 ✨ lfo M version
2022-08-11 ✨ harmonic syncs
2022-08-25 🚚 folder name
2022-09-09 ✨ add ramp mode to harmonic lfos
2022-09-10 ⚰️ delete files
2022-09-10 🎉 publish m14
2022-09-10 🎉 docs m14
    [Drill_NPTH_Through.DRL, Drill_PTH_Through.DRL, Gerber_BoardOutlineLayer.GKO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]
2022-09-10 🚀 model 15
2022-09-10 📝 typos
2022-09-14 ⚗️ board definition
2022-09-14 🍱 export model 14 to altium
    [model_14.pcbdoc, model_14.schdoc]
2022-10-12 🍱 Update Gerbers
    [Drill_NPTH_Through.DRL, Drill_PTH_Through.DRL, Gerber_BoardOutlineLayer.GKO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]
2022-10-13 📝 new model 14 photo
2022-10-13 🎉 chrono trigger
2022-10-14 :memo: Complete BOM
2022-10-14 :pencil: Complete BOM list
2022-10-14 :pencil2: Oled bom name
2022-10-15 ✨ knob paired cv class
2022-10-15 ⚗️ Beat algorithm working
2022-10-18 🚧 adding Beat to CT
2022-10-18 🎉 PRoject 32 OSC
2022-10-23 ✨ Beats (unlinked) working
2022-11-17 🚚 branch proto branch
2022-11-17 ⚗️ 📝 Pages
